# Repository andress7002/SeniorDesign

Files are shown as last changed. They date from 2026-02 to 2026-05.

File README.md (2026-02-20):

# Portable Power Station

This repository contains the hardware and software design files for our Senior Design Project at UTRGV. 

## Overview
Current portable power stations often suffer from poor State-of-Charge (SOC) estimation, inaccurate runtime predictions, and binary failure modes. Our primary objective is to solve this by designing and building an intelligent portable power station that delivers accurate, predictive battery statistics alongside early warnings and predictive thermal management. 

Unlike affordable commercial alternatives, our design integrates a custom high-precision Monitoring Board. This allows for real-time tracking of input/output current, individual cell voltages, and precise battery temperatures to provide an accurate State of Charge (SoC) and true State of Health (SoH).

## Key Specifications
* **Battery Capacity:** 40Ah total capacity utilizing a 3S8P configuration of EVE 50E 21700 cells.
* **Power Outputs:**  120W car lighter output (10A @ 12V)
  * 100W USB-C Power Delivery port
  * 65W USB-C standard port
  * Dual 12W USB-A ports
* **Safety:** Multi-layer protection combining a Daly 40A Battery Management System (BMS) with our custom monitoring board and active cooling.

## System Architecture
The system is controlled by an **STM32F103C8Tx Blue Pill** microcontroller. To simplify the design and communication path, all digital monitors, including the ADCs and the OLED screen, are hosted on a single I2C channel.

**Key Components:**
* **Current Monitoring:** INA series sensor (INA226/INA228) for highly accurate, bidirectional power measurement.
* **Voltage Sensing:** MCP6004 Op-Amp configured for true rail-to-rail I/O to safely step down the maximum cell voltage for the STM32's ADC.
* **Thermal Monitoring:** ADS1115 paired with NTC 10k thermistors to track cell temperatures across the pack.
* **User Interface:** An upgraded OLED display provides real-time feedback to the user on changing battery values.
* **Hardware Integration:** All power, sensing, and control components are being integrated into a custom-manufactured PCB.

## Team Members
* Gonzalo Cervera-Aguinaga
* Darren Mora
* Javier Castro-Frausto
* Andres Sierra Cantu

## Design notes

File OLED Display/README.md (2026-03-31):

# STM32F103C8T6 — SSD1306 OLED Sensor Display

## Wiring

| OLED Pin | STM32 Pin |
|---|---|
| VCC | 3.3V |
| GND | GND |
| SCL | PB6 |
| SDA | PB7 |

| Signal | STM32 Pin |
|---|---|
| External Voltage | PA1 |

---

## What the screen shows

```
┌────────────────────────┐
│    STM32 Sensors       │
│ Temp: 27.4 C           │
│ V_ch1: 1.412 V         │
│ V_ch2: 1.650 V         │
└────────────────────────┘
```

- **Temp** — STM32 internal temperature sensor (~±5°C accuracy)
- **V_ch1** — raw voltage from the internal sensor
- **V_ch2** — voltage measured on PA1 (0 to 3.3V)

Refreshes every 200ms.

---

## Troubleshooting

| Symptom | Fix |
|---|---|
| Blank screen | Check SDA/SCL wiring on PB7/PB6 |
| Wrong temperature | Normal — internal sensor varies per chip |
| V_ch2 always 0 | Check your signal is connected to PA1 |

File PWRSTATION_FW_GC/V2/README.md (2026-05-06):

# PWRSTATION_FW

Bare-metal firmware for an STM32F103C8T6 (Blue Pill) power monitoring station. Reads voltage, current, power, temperature, energy, and charge from a Texas Instruments INA228 85V precision power monitor and displays real-time engineering values on a DIYmall 0.96" SSD1306 I2C OLED display.

---

## Hardware

| Component | Part | Notes |
|---|---|---|
| Microcontroller | STM32F103C8T6 (Blue Pill) | 8 MHz HSI, no PLL |
| Power monitor IC | Texas Instruments INA228 | I2C address 0x40 (A0=A1=GND) |
| Display | DIYmall 0.96" SSD1306 128×64 OLED | I2C address 0x3C |
| Programmer | ST-Link V2 clone | SWD interface |
| Shunt resistor | 1 mΩ | Rated for max expected current |
| Pull-up resistors | 2.2 kΩ × 2 | SDA and SCL to 3.3V rail |

### Pin assignments

| Blue Pill pin | Function | Connected to |
|---|---|---|
| PB6 | I2C1 SCL | INA228 SCL, OLED SCL (shared bus) |
| PB7 | I2C1 SDA | INA228 SDA, OLED SDA (shared bus) |
| PC13 | Onboard LED (active-LOW) | Fault indicator / boot blink |
| PA13 | SWDIO | ST-Link SWDIO |
| PA14 | SWCLK | ST-Link SWCLK |

### INA228 wiring (high-side sensing)

```
Battery+ ──── VBUS
Battery+ ──── IN+  ──── [Rshunt 1mΩ] ──── IN- ──── Load
INA228 VS ─── 3.3V (Blue Pill)
INA228 GND ── GND
INA228 A0 ─── GND  (address bit 0)
INA228 A1 ─── GND  (address bit 1)
INA228 ALERT ─ NC  (not connected)
```

### I2C bus

Both devices share I2C1 on PB6/PB7. Pull-up resistors must connect from each line to the **3.3V rail** — not 5V. 2.2 kΩ gives a calculated rise time of ~186 ns, comfortably within the 300 ns Fast-mode budget.

---

## Software architecture

The firmware is structured as a non-blocking cooperative scheduler driven by `HAL_GetTick()` (1 ms Systick). There is no RTOS.

### Source file structure

```
PWRSTATION_FW/
├── Core/
│   ├── Inc/
│   │   └── main.h                  STM32 HAL includes and Error_Handler declaration
│   └── Src/
│       ├── main.c                  Application entry point and scheduler
│       ├── stm32f1xx_hal_msp.c     HAL peripheral MSP init (GPIO AF, RCC clocks)
│       ├── stm32f1xx_it.c          Interrupt handlers (SysTick_Handler etc.)
│       ├── syscalls.c              Newlib syscall stubs (_write, _read, etc.)
│       └── sysmem.c                Heap implementation for newlib
├── Core/DriversExt/
│   ├── ina228/
│   │   ├── ina228.h                INA228 driver public API and struct definition
│   │   ├── ina228.c                INA228 driver implementation
│   │   └── ina228_regs.h           INA228 register map and bit-field constants
│   └── oled/
│       ├── oled.h                  SSD1306 OLED driver public API
│       └── oled.c                  SSD1306 driver: init, frame buffer, text rendering
├── Drivers/
│   ├── STM32F1xx_HAL_Driver/       STM32 HAL library (ST-provided, do not edit)
│   └── CMSIS/                      ARM CMSIS headers (ST-provided, do not edit)
├── cmake/                          CMake toolchain files generated by STM32CubeMX
├── CMakeLists.txt                  Build system — add new source files here
├── CMakePresets.json               Debug/Release preset configuration
├── STM32F103C8TX_FLASH.ld          Linker script for 64KB flash / 20KB RAM
└── PWRSTATION_FW.ioc               STM32CubeMX project file
```

### Key files explained

**`main.c`** is the application layer. It contains three logical sections:

- `app_init()` — runs once at boot. Initialises the OLED and INA228 over I2C, verifies the INA228 silicon ID, configures the ADC mode and averaging, and resets the energy/charge accumulators. Uses PC13 LED blink codes to signal fault conditions without needing a serial monitor.
- `app_fast_task()` — called every 500 ms by the scheduler. Reads VBUS voltage, shunt voltage, current, power, and die temperature from the INA228 and writes them to OLED rows 0–3.
- `app_slow_task()` — called every 5000 ms. Reads the 40-bit energy and charge accumulators from the INA228 and writes them to OLED rows 4–5.

**`ina228.h` / `ina228.c`** implement the INA228 driver as a self-contained module. The public API covers initialisation, ADC configuration, accumulator reset, and all engineering-unit reads (V, I, P, T, E, Q). All I2C transactions use a finite 500 ms timeout (`INA228_I2C_TIMEOUT_MS`) so the firmware never hangs when the device is absent. A `_i2c_reset()` helper recovers the STM32F1 I2C peripheral from the hardware BUSY lockup bug after any timeout.

**`ina228_regs.h`** defines every INA228 register address and bit-field constant with the `INA228_REG_` prefix to avoid name collisions. Constants cover the full CONFIG, ADC_CONFIG, DIAG_ALRT register maps and known silicon ID values.

**`oled.h` / `oled.c`** implement the SSD1306 OLED driver in two layers. Layer 1 covers hardware primitives: `oled_init()` (full SSD1306 init sequence including charge pump), `oled_flush()` (single 1025-byte I2C burst using horizontal addressing mode), `oled_set_pixel()`, and line/rect drawing helpers. Layer 2 covers text rendering: `oled_print_str()` renders ASCII characters from an embedded 5×7 font stored in Flash, and `oled_printf_row()` formats a full 21-character row using `vsnprintf` and overwrites the entire row to prevent stale digit artifacts.

---

## Scheduler

The main loop is a simple non-blocking timer check with no blocking calls:

```c
while (1)
{
    if (ms_elapsed(s_t_fast) >= INTERVAL_FAST_MS)
    {
        s_t_fast = HAL_GetTick();
        app_fast_task();             // 500 ms: V, I, P, T
    }
    if (ms_elapsed(s_t_slow) >= INTERVAL_SLOW_MS)
    {
        s_t_slow = HAL_GetTick();
        app_slow_task();             // 5000 ms: Energy, Charge
    }
}
```

`ms_elapsed()` handles the 32-bit `HAL_GetTick()` rollover at ~49.7 days of uptime.

---

## Fault blink codes (PC13 LED)

| Pattern | Meaning |
|---|---|
| 3 fast (80 ms) | MCU alive — boot reached app_init |
| 7 medium (200 ms) | OLED not responding on I2C |
| 10 medium (200 ms) | INA228 not responding on I2C |
| 3 medium (200 ms) | INA228 found but silicon ID mismatch |

All faults are non-fatal. The firmware continues running in degraded mode after signalling the fault code.

---

## OLED display layout

```
Row 0   V:  12.345 V     bus voltage
Row 1   I:   3.456 A     load current
Row 2   P:  42.345 W     power
Row 3   T:   27.5 C      INA228 die temperature
Row 4   E: 1234.5 J      energy accumulator
Row 5   Q:  567.8 C      charge accumulator
Row 6   (reserved)
Row 7   (reserved)
```

Font: 5×7 pixel glyphs with 1-pixel column gap, 6 px per character, 21 characters × 8 rows on 128×64.

---

## INA228 configuration

| Parameter | Value | Notes |
|---|---|---|
| Shunt resistance | 1 mΩ | `INA228_SHUNT_OHMS` in main.c |
| Max expected current | 40 A | `INA228_MAX_AMPS` in main.c |
| Current LSB | ~76.3 nA/LSB | Computed as Imax / 2^19 |
| ADC mode | Continuous all | Shunt + bus + temperature |
| Conversion time | 1052 µs | Per channel |
| Averaging | 64 samples | ~67 ms total conversion cycle |
| I2C address | 0x40 | A0=GND, A1=GND |

To change shunt resistance or current range, update only the two defines in `main.c`. The driver recomputes `SHUNT_CAL`, `current_lsb`, and `power_lsb` automatically.

---

## Build environment

| Tool | Version |
|---|---|
| IDE | VS Code + STM32CubeMX VS Code extension |
| Compiler | GNU Arm Embedded Toolchain (arm-none-eabi-gcc) 13.3.1 |
| Build system | CMake 4.0 + Ninja |
| HAL | STM32F1xx HAL Driver (CubeMX generated) |
| Language standard | C11 |

### Building

Clone the repository, open the folder in VS Code with the STM32CubeMX extension installed, and click **Build**. The extension handles CMake configuration automatically using `CMakePresets.json`.

To rebuild from scratch delete the `build/` directory and rebuild.

### Flashing

Connect the ST-Link V2 to the Blue Pill SWD header (SWDIO → PA13, SWCLK → PA14, 3.3V, GND), then click **Run and Debug** in VS Code. Verify BOOT0 jumper is set to 0 (GND) before flashing.

### Modifying CubeMX configuration

Open `PWRSTATION_FW.ioc` in STM32CubeMX. After making changes click **Generate Code**. CubeMX preserves all user code inside `/* USER CODE BEGIN */` / `/* USER CODE END */` markers. Always back up `main.c` before regenerating as a precaution.

---

## Adding this repository's driver files after CubeMX regeneration

CubeMX does not know about `Core/DriversExt/`. After regenerating, verify `CMakeLists.txt` still contains these entries:

```cmake
target_sources(${CMAKE_PROJECT_NAME} PRIVATE
    ...
    Core/DriversExt/ina228/ina228.c
    Core/DriversExt/oled/oled.c
)

target_include_directories(${CMAKE_PROJECT_NAME} PRIVATE
    ...
    Core/DriversExt/ina228
    Core/DriversExt/oled
)
```

CubeMX will not remove these lines (they are outside its managed sections) but it may reformat the file — verify after every regeneration.

---

## License

STM32 HAL library files under `Drivers/` are copyright STMicroelectronics and licensed under BSD 3-Clause. Application code in `Core/` and `Core/DriversExt/` is provided as-is.

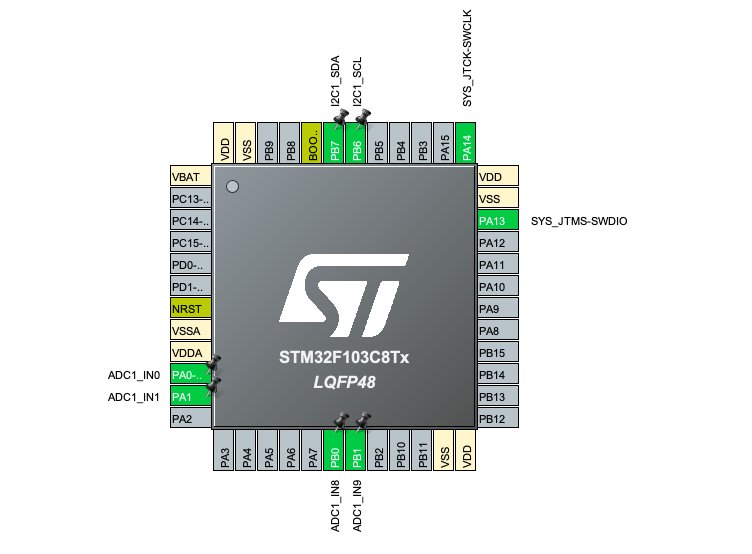
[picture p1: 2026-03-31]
OLED Display/cubemx_pinout.png

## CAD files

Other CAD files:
PCB Design/SENIOR_DESIGN_CASE.f3d
PCB Design/SENIOR_FINAL_CASE.f3d
PCB Design/SENIOR_FINAL_CASE_UPDATE1.f3d

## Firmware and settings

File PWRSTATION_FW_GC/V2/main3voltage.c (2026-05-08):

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

/* Includes ------------------------------------------------------------------*/
/* USER CODE BEGIN Includes */
#include "main.h"
#include <stdio.h>
#include <math.h>
#include "ina228.h"
#include "oled.h"
/* USER CODE END Includes */

/* USER CODE BEGIN PD */

/* -- INA228 ----------------------------------------------------------------- */
#define INA228_I2C_ADDR    0x40
#define INA228_SHUNT_OHMS  0.001f
#define INA228_MAX_AMPS    40.0f

/* -- OLED ------------------------------------------------------------------- */
#define OLED_I2C_ADDR      0x3C

/* -- Scheduler intervals ---------------------------------------------------- */
#define INTERVAL_FAST_MS   500U
#define INTERVAL_SLOW_MS   5000U

/* -- NTC thermistor parameters ---------------------------------------------- */
#define R_FIXED        10000.0f
#define R_NOMINAL      11000.0f
#define T_NOMINAL      25.0f
#define B_COEFFICIENT  3950.0f
#define V_SUPPLY       3.3f
#define ADC_RESOLUTION 4095.0f

/* -- Cell voltage sensing (MCP6004 gain = 2/3, so inverse = x1.5) ---------- */
#define CELL_GAIN_INV  1.5f
#define CELL_VOLT_MIN  2.5f
#define CELL_VOLT_MAX  4.2f

/* USER CODE END PD */

/* USER CODE BEGIN PM */
#define LED_ON()   HAL_GPIO_WritePin(GPIOC, GPIO_PIN_13, GPIO_PIN_RESET)
#define LED_OFF()  HAL_GPIO_WritePin(GPIOC, GPIO_PIN_13, GPIO_PIN_SET)
#define LED_TOG()  HAL_GPIO_TogglePin(GPIOC, GPIO_PIN_13)
/* USER CODE END PM */

ADC_HandleTypeDef  hadc1;
I2C_HandleTypeDef  hi2c1;
TIM_HandleTypeDef  htim1;
UART_HandleTypeDef huart1;

/* USER CODE BEGIN PV */

/* -- INA228 ----------------------------------------------------------------- */
static ina228_t  g_ina;
static uint8_t   g_ina_ok   = 0U;

volatile float   g_current_A = 0.0f;
volatile float   g_power_W   = 0.0f;
volatile float   g_dietemp_C = 0.0f;
volatile double  g_energy_J  = 0.0;
volatile double  g_charge_C  = 0.0;
volatile uint8_t g_ina_err   = 0U;

/* -- Cell voltages (PA2=C1, PA3=C2, PA4=C3) -------------------------------- */
volatile float   g_vcell1    = 0.0f;
volatile float   g_vcell2    = 0.0f;
volatile float   g_vcell3    = 0.0f;

/* -- NTC thermistors (PA0=T1, PA1=T2) -------------------------------------- */
volatile float   temp_t1     = 0.0f;
volatile float   temp_t2     = 0.0f;

/* -- Scheduler timestamps --------------------------------------------------- */
static uint32_t s_t_fast = 0U;
static uint32_t s_t_slow = 0U;

/* USER CODE END PV */

void SystemClock_Config(void);
static void MX_GPIO_Init(void);
static void MX_ADC1_Init(void);
static void MX_I2C1_Init(void);
static void MX_TIM1_Init(void);
static void MX_USART1_UART_Init(void);

/* USER CODE BEGIN PFP */
static void     led_blink(uint8_t count, uint32_t on_ms, uint32_t off_ms);
static void     app_init(void);
static void     app_fast_task(void);
static void     app_slow_task(void);
static uint32_t ms_elapsed(uint32_t since);
static void     I2C1_BusRecovery(void);
static uint8_t  ADC_SelectChannel(uint32_t channel);
static uint16_t ADC_ReadRaw(uint32_t channel);
static float    NTC_ToTemperature(float v);
static float    CellADC_ToVoltage(uint32_t channel);
/* USER CODE END PFP */

/* USER CODE BEGIN 0 */

static uint32_t ms_elapsed(uint32_t since)
{
    uint32_t now = HAL_GetTick();
    return (now >= since) ? (now - since)
                          : (0xFFFFFFFFU - since + now + 1U);
}

static void led_blink(uint8_t count, uint32_t on_ms, uint32_t off_ms)
{
    for (uint8_t i = 0; i < count; i++)
    {
        LED_ON();  HAL_Delay(on_ms);
        LED_OFF(); HAL_Delay(off_ms);
    }
}

static uint8_t ADC_SelectChannel(uint32_t channel)
{
    ADC_ChannelConfTypeDef sConfig = {0};
    sConfig.Channel      = channel;
    sConfig.Rank         = ADC_REGULAR_RANK_1;
    sConfig.SamplingTime = ADC_SAMPLETIME_239CYCLES_5;
    if (HAL_ADC_ConfigChannel(&hadc1, &sConfig) != HAL_OK)
        return 0;
    return 1;
}

static uint16_t ADC_ReadRaw(uint32_t channel)
{
    if (!ADC_SelectChannel(channel)) return 0;
    if (HAL_ADC_Start(&hadc1) != HAL_OK) return 0;
    if (HAL_ADC_PollForConversion(&hadc1, 100U) != HAL_OK)
    {
        HAL_ADC_Stop(&hadc1);
        return 0;
    }
    uint16_t val = (uint16_t)HAL_ADC_GetValue(&hadc1);
    HAL_ADC_Stop(&hadc1);
    return val;
}

static float NTC_ToTemperature(float v)
{
    if (v >= V_SUPPLY) return -273.15f;
    if (v <= 0.0f)     return -273.15f;
    float r_ntc     = R_FIXED * v / (V_SUPPLY - v);
    float steinhart = logf(r_ntc / R_NOMINAL);
    steinhart /= B_COEFFICIENT;
    steinhart += 1.0f / (T_NOMINAL + 273.15f);
    steinhart  = 1.0f / steinhart;
    return steinhart - 273.15f;
}

static float CellADC_ToVoltage(uint32_t channel)
{
    uint16_t raw = ADC_ReadRaw(channel);
    float    v   = ((float)raw * V_SUPPLY) / ADC_RESOLUTION;
    return v * CELL_GAIN_INV;   /* undo MCP6004 2/3 gain */
}

/* ── Application tasks ──────────────────────────────────────────────────── */

static void app_init(void)
{
    led_blink(3, 80, 80);
    HAL_Delay(400);

    oled_status_t oled_s = oled_init(&hi2c1, OLED_I2C_ADDR);
    if (oled_s != OLED_OK)
    {
        led_blink(7, 200, 200);
    }
    else
    {
        oled_clear();
        oled_print_str(0, 0, "PWRSTATION FW");
        oled_print_str(0, 1, "Init...");
        oled_flush();
    }

    ina228_status_t ina_s = ina228_init(&g_ina, &hi2c1,
                                         INA228_I2C_ADDR,
                                         INA228_SHUNT_OHMS,
                                         INA228_MAX_AMPS);
    if (ina_s != INA228_OK)
    {
        led_blink(10, 200, 200);
        g_ina_ok = 0U;
        if (oled_s == OLED_OK)
        {
            oled_clear();
            oled_print_str(0, 0, "INA228 MISSING");
            oled_print_str(0, 1, "Cell+NTC only");
            oled_flush();
            HAL_Delay(2000);
        }
        return;
    }

    if (ina228_check_id(&g_ina) != INA228_OK)
    {
        led_blink(3, 200, 200);
        g_ina_ok = 0U;
        if (oled_s == OLED_OK)
        {
            oled_clear();
            oled_print_str(0, 0, "INA228 BAD ID");
            oled_flush();
            HAL_Delay(2000);
        }
        return;
    }

    ina228_set_adc_config(&g_ina,
        INA228_REG_MODE_CONT_ALL |
        INA228_REG_VBUSCT_1052US |
        INA228_REG_VSHCT_1052US  |
        INA228_REG_VTCT_1052US   |
        INA228_REG_AVG_64);

    ina228_reset_accumulators(&g_ina);
    g_ina_ok = 1U;

    if (oled_s == OLED_OK)
    {
        oled_clear();
        oled_print_str(0, 0, "PWRSTATION FW");
        oled_print_str(0, 1, "INA228 OK");
        oled_flush();
        HAL_Delay(1000);
    }
}

/**
  * @brief  Fast task — 500 ms cadence.
  *
  *   Row 0  C1:  3.712 V       Cell 1 (PA2)   [!! CELL FAULT !! if out of range]
  *   Row 1  C2:  3.708 V       Cell 2 (PA3)
  *   Row 2  C3:  3.715 V       Cell 3 (PA4)
  *   Row 3  I:   3.4560 A      INA228 current
  *   Row 4  P:  42.345 W       INA228 power
  *   Row 5  E: 1234.5  J       INA228 energy  (written by slow task)
  *   Row 6  T1:  25.3 C        NTC thermistor 1 (PA0)
  *   Row 7  T2:  31.7 C        NTC thermistor 2 (PA1)
  */
static void app_fast_task(void)
{
    /* ── Cell voltages (PA2/PA3/PA4) -> rows 0-2 ─────────────────────────── */
    g_vcell1 = CellADC_ToVoltage(ADC_CHANNEL_2);
    g_vcell2 = CellADC_ToVoltage(ADC_CHANNEL_3);
    g_vcell3 = CellADC_ToVoltage(ADC_CHANNEL_4);

    uint8_t cell_fault = (g_vcell1 < CELL_VOLT_MIN || g_vcell1 > CELL_VOLT_MAX ||
                          g_vcell2 < CELL_VOLT_MIN || g_vcell2 > CELL_VOLT_MAX ||
                          g_vcell3 < CELL_VOLT_MIN || g_vcell3 > CELL_VOLT_MAX) ? 1U : 0U;

    if (cell_fault)
        oled_printf_row(0, "!! CELL FAULT !!");
    else
        oled_printf_row(0, "C1:%6.3fV", (double)g_vcell1);

    oled_printf_row(1, "C2:%6.3fV", (double)g_vcell2);
    oled_printf_row(2, "C3:%6.3fV", (double)g_vcell3);

    /* ── INA228 current + power -> rows 3-4 ─────────────────────────────── */
    if (g_ina_ok)
    {
        ina228_status_t s = INA228_OK;
        s |= ina228_get_current_A(&g_ina, (float *)&g_current_A);
        s |= ina228_get_power_W  (&g_ina, (float *)&g_power_W);
        s |= ina228_get_dietemp_C(&g_ina, (float *)&g_dietemp_C);

        if (s != INA228_OK)
        {
            g_ina_err++;
            oled_printf_row(3, "INA228 ERR");
            oled_printf_row(4, "");
        }
        else
        {
            g_ina_err = 0U;
            oled_printf_row(3, "I:%7.4fA", (double)g_current_A);
            oled_printf_row(4, "P:%7.3fW",  (double)g_power_W);
        }
    }
    else
    {
        oled_printf_row(3, "I:    --- A");
        oled_printf_row(4, "P:    --- W");
    }

    /* ── NTC thermistors (PA0=T1, PA1=T2) -> rows 6-7 ───────────────────── */
    temp_t1 = NTC_ToTemperature(((float)ADC_ReadRaw(ADC_CHANNEL_0) * V_SUPPLY) / ADC_RESOLUTION);
    temp_t2 = NTC_ToTemperature(((float)ADC_ReadRaw(ADC_CHANNEL_1) * V_SUPPLY) / ADC_RESOLUTION);

    oled_printf_row(6, "T1:%5.1fC", (double)temp_t1);
    oled_printf_row(7, "T2:%5.1fC", (double)temp_t2);

    oled_flush();
}

/**
  * @brief  Slow task — 5000 ms cadence.  Energy accumulator -> row 5.
  */
static void app_slow_task(void)
{
    if (!g_ina_ok) return;

    ina228_status_t s = INA228_OK;
    s |= ina228_get_energy_J(&g_ina, (double *)&g_energy_J);
    s |= ina228_get_charge_C(&g_ina, (double *)&g_charge_C);

    if (s != INA228_OK) { g_ina_err++; return; }

    oled_printf_row(5, "E:%7.1fJ", g_energy_J);
    oled_flush();
}

static void I2C1_BusRecovery(void)
{
    GPIO_InitTypeDef GPIO_InitStruct = {0};

    __HAL_RCC_GPIOB_CLK_ENABLE();
    __HAL_RCC_I2C1_FORCE_RESET();
    HAL_Delay(10);
    __HAL_RCC_I2C1_RELEASE_RESET();

    GPIO_InitStruct.Pin   = GPIO_PIN_6 | GPIO_PIN_7;
    GPIO_InitStruct.Mode  = GPIO_MODE_OUTPUT_OD;
    GPIO_InitStruct.Pull  = GPIO_NOPULL;
    GPIO_InitStruct.Speed = GPIO_SPEED_FREQ_LOW;
    HAL_GPIO_Init(GPIOB, &GPIO_InitStruct);

    HAL_GPIO_WritePin(GPIOB, GPIO_PIN_6 | GPIO_PIN_7, GPIO_PIN_SET);
    HAL_Delay(1);

    for (uint8_t i = 0; i < 9; i++)
    {
        HAL_GPIO_WritePin(GPIOB, GPIO_PIN_6, GPIO_PIN_RESET);
        HAL_Delay(1);
        HAL_GPIO_WritePin(GPIOB, GPIO_PIN_6, GPIO_PIN_SET);
        HAL_Delay(1);
        if (HAL_GPIO_ReadPin(GPIOB, GPIO_PIN_7) == GPIO_PIN_SET)
            break;
    }

    HAL_GPIO_WritePin(GPIOB, GPIO_PIN_7, GPIO_PIN_RESET);
    HAL_Delay(1);
    HAL_GPIO_WritePin(GPIOB, GPIO_PIN_6, GPIO_PIN_SET);
    HAL_Delay(1);
    HAL_GPIO_WritePin(GPIOB, GPIO_PIN_7, GPIO_PIN_SET);
    HAL_Delay(1);

    HAL_GPIO_DeInit(GPIOB, GPIO_PIN_6 | GPIO_PIN_7);
}

/* USER CODE END 0 */

int main(void)
{
    HAL_Init();
    SystemClock_Config();

    /* USER CODE BEGIN SysInit */
    I2C1_BusRecovery();
    /* USER CODE END SysInit */

    MX_GPIO_Init();
    MX_ADC1_Init();
    MX_I2C1_Init();
    MX_TIM1_Init();
    MX_USART1_UART_Init();

    /* USER CODE BEGIN 2 */
    app_init();
    s_t_fast = HAL_GetTick();
    s_t_slow = HAL_GetTick();
    /* USER CODE END 2 */

    while (1)
    {
        /* USER CODE BEGIN 3 */
        if (ms_elapsed(s_t_fast) >= INTERVAL_FAST_MS)
        {
            s_t_fast = HAL_GetTick();
            LED_TOG();
            app_fast_task();
        }

        if (ms_elapsed(s_t_slow) >= INTERVAL_SLOW_MS)
        {
            s_t_slow = HAL_GetTick();
            app_slow_task();
        }
        /* USER CODE END 3 */
    }
}

void SystemClock_Config(void)
{
    RCC_OscInitTypeDef       RCC_OscInitStruct = {0};
    RCC_ClkInitTypeDef       RCC_ClkInitStruct = {0};
    RCC_PeriphCLKInitTypeDef PeriphClkInit     = {0};

    RCC_OscInitStruct.OscillatorType      = RCC_OSCILLATORTYPE_HSI;
    RCC_OscInitStruct.HSIState            = RCC_HSI_ON;
    RCC_OscInitStruct.HSICalibrationValue = RCC_HSICALIBRATION_DEFAULT;
    RCC_OscInitStruct.PLL.PLLState        = RCC_PLL_NONE;
    if (HAL_RCC_OscConfig(&RCC_OscInitStruct) != HAL_OK)
        Error_Handler();

    RCC_ClkInitStruct.ClockType      = RCC_CLOCKTYPE_HCLK | RCC_CLOCKTYPE_SYSCLK
                                     | RCC_CLOCKTYPE_PCLK1 | RCC_CLOCKTYPE_PCLK2;
    RCC_ClkInitStruct.SYSCLKSource   = RCC_SYSCLKSOURCE_HSI;
    RCC_ClkInitStruct.AHBCLKDivider  = RCC_SYSCLK_DIV1;
    RCC_ClkInitStruct.APB1CLKDivider = RCC_HCLK_DIV1;
    RCC_ClkInitStruct.APB2CLKDivider = RCC_HCLK_DIV1;
    if (HAL_RCC_ClockConfig(&RCC_ClkInitStruct, FLASH_LATENCY_0) != HAL_OK)
        Error_Handler();

    PeriphClkInit.PeriphClockSelection = RCC_PERIPHCLK_ADC;
    PeriphClkInit.AdcClockSelection    = RCC_ADCPCLK2_DIV2;
    if (HAL_RCCEx_PeriphCLKConfig(&PeriphClkInit) != HAL_OK)
        Error_Handler();
}

static void MX_ADC1_Init(void)
{
    ADC_ChannelConfTypeDef sConfig = {0};

    hadc1.Instance                   = ADC1;
    hadc1.Init.ScanConvMode          = ADC_SCAN_DISABLE;
    hadc1.Init.ContinuousConvMode    = DISABLE;
    hadc1.Init.DiscontinuousConvMode = DISABLE;
    hadc1.Init.ExternalTrigConv      = ADC_SOFTWARE_START;
    hadc1.Init.DataAlign             = ADC_DATAALIGN_RIGHT;
    hadc1.Init.NbrOfConversion       = 1;
    if (HAL_ADC_Init(&hadc1) != HAL_OK)
        Error_Handler();

    /* Default CH0 (PA0/T1) — ADC_SelectChannel() overrides at runtime
     * Channels in use:
     *   CH0 (PA0) T1 NTC
     *   CH1 (PA1) T2 NTC
     *   CH2 (PA2) Cell 1 op-amp output
     *   CH3 (PA3) Cell 2 op-amp output
     *   CH4 (PA4) Cell 3 op-amp output        */
    sConfig.Channel      = ADC_CHANNEL_0;
    sConfig.Rank         = ADC_REGULAR_RANK_1;
    sConfig.SamplingTime = ADC_SAMPLETIME_239CYCLES_5;
    if (HAL_ADC_ConfigChannel(&hadc1, &sConfig) != HAL_OK)
        Error_Handler();
}

static void MX_I2C1_Init(void)
{
    hi2c1.Instance             = I2C1;
    hi2c1.Init.ClockSpeed      = 400000;
    hi2c1.Init.DutyCycle       = I2C_DUTYCYCLE_2;
    hi2c1.Init.OwnAddress1     = 0;
    hi2c1.Init.AddressingMode  = I2C_ADDRESSINGMODE_7BIT;
    hi2c1.Init.DualAddressMode = I2C_DUALADDRESS_DISABLE;
    hi2c1.Init.OwnAddress2     = 0;
    hi2c1.Init.GeneralCallMode = I2C_GENERALCALL_DISABLE;
    hi2c1.Init.NoStretchMode   = I2C_NOSTRETCH_DISABLE;
    if (HAL_I2C_Init(&hi2c1) != HAL_OK)
        Error_Handler();
}

static void MX_TIM1_Init(void)
{
    TIM_ClockConfigTypeDef  sClockSourceConfig = {0};
    TIM_MasterConfigTypeDef sMasterConfig      = {0};

    htim1.Instance               = TIM1;
    htim1.Init.Prescaler         = 7;
    htim1.Init.CounterMode       = TIM_COUNTERMODE_UP;
    htim1.Init.Period            = 65535;
    htim1.Init.ClockDivision     = TIM_CLOCKDIVISION_DIV1;
    htim1.Init.RepetitionCounter = 0;
    htim1.Init.AutoReloadPreload = TIM_AUTORELOAD_PRELOAD_DISABLE;
    if (HAL_TIM_Base_Init(&htim1) != HAL_OK)
        Error_Handler();

    sClockSourceConfig.ClockSource = TIM_CLOCKSOURCE_INTERNAL;
    if (HAL_TIM_ConfigClockSource(&htim1, &sClockSourceConfig) != HAL_OK)
        Error_Handler();

    sMasterConfig.MasterOutputTrigger = TIM_TRGO_RESET;
    sMasterConfig.MasterSlaveMode     = TIM_MASTERSLAVEMODE_DISABLE;
    if (HAL_TIMEx_MasterConfigSynchronization(&htim1, &sMasterConfig) != HAL_OK)
        Error_Handler();

    HAL_TIM_Base_Start(&htim1);
}

static void MX_USART1_UART_Init(void)
{
    huart1.Instance          = USART1;
    huart1.Init.BaudRate     = 115200;
    huart1.Init.WordLength   = UART_WORDLENGTH_8B;
    huart1.Init.StopBits     = UART_STOPBITS_1;
    huart1.Init.Parity       = UART_PARITY_NONE;
    huart1.Init.Mode         = UART_MODE_TX_RX;
    huart1.Init.HwFlowCtl    = UART_HWCONTROL_NONE;
    huart1.Init.OverSampling = UART_OVERSAMPLING_16;
    if (HAL_UART_Init(&huart1) != HAL_OK)
        Error_Handler();
}

static void MX_GPIO_Init(void)
{
    GPIO_InitTypeDef GPIO_InitStruct = {0};

    __HAL_RCC_GPIOC_CLK_ENABLE();
    __HAL_RCC_GPIOA_CLK_ENABLE();
    __HAL_RCC_GPIOB_CLK_ENABLE();

    /* PC13 — onboard LED, active-LOW */
    HAL_GPIO_WritePin(GPIOC, GPIO_PIN_13, GPIO_PIN_SET);
    GPIO_InitStruct.Pin   = GPIO_PIN_13;
    GPIO_InitStruct.Mode  = GPIO_MODE_OUTPUT_PP;
    GPIO_InitStruct.Pull  = GPIO_NOPULL;
    GPIO_InitStruct.Speed = GPIO_SPEED_FREQ_LOW;
    HAL_GPIO_Init(GPIOC, &GPIO_InitStruct);

    /* PA0-PA4 left as analog inputs — HAL_ADC_Init() configures them.
     * Do NOT drive these pins as digital outputs.                     */
}

void Error_Handler(void)
{
    __disable_irq();
    while (1) { }
}

#ifdef USE_FULL_ASSERT
void assert_failed(uint8_t *file, uint32_t line)
{
    (void)file; (void)line;
}
#endif

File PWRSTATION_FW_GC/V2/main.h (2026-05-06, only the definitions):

#define GREEN_LED_Pin GPIO_PIN_13
#define GREEN_LED_GPIO_Port GPIOC
#define OLED_RST_Pin GPIO_PIN_0
#define OLED_RST_GPIO_Port GPIOA

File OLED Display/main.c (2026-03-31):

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
/* Includes ------------------------------------------------------------------*/
#include "main.h"

/* USER CODE BEGIN Includes */
#include "ssd1306.h"
#include "ssd1306_fonts.h"
#include <stdio.h>  // for sprintf
/* USER CODE END Includes */

ADC_HandleTypeDef hadc1;

I2C_HandleTypeDef hi2c1;

/* USER CODE BEGIN PV */

static char display_buf[32];  // scratch buffer for sprintf

#define STM32_SENSOR_1_CHANNEL  ADC_CHANNEL_TEMPSENSOR
#define STM32_SENSOR_2_CHANNEL  ADC_CHANNEL_1

static uint16_t raw_ch1 = 0;
static uint16_t raw_ch2 = 0;
static float voltage_ch1 = 0.0f;
static float voltage_ch2 = 0.0f;

static float temp_ch1 = 0.0f;
/* USER CODE END PV */

void SystemClock_Config(void);
static void MX_GPIO_Init(void);
static void MX_ADC1_Init(void);
static void MX_I2C1_Init(void);
/* USER CODE BEGIN PFP */
static uint8_t STM32_ADC_SelectChannel(uint32_t channel);
static uint16_t STM32_ADC_ReadRaw(uint32_t channel);
static float STM32_ADC_RawToVoltage(uint16_t raw);
/* USER CODE END PFP */

/* USER CODE BEGIN 0 */
static uint8_t STM32_ADC_SelectChannel(uint32_t channel)
{
  ADC_ChannelConfTypeDef sConfig = {0};

  sConfig.Channel = channel;
  sConfig.Rank = ADC_REGULAR_RANK_1;
  sConfig.SamplingTime = ADC_SAMPLETIME_239CYCLES_5;

  if (HAL_ADC_ConfigChannel(&hadc1, &sConfig) != HAL_OK)
  {
    return 0;
  }

  return 1;
}

static uint16_t STM32_ADC_ReadRaw(uint32_t channel)
{
  if (!STM32_ADC_SelectChannel(channel))
  {
    return 0;
  }

  if (HAL_ADC_Start(&hadc1) != HAL_OK)
  {
    return 0;
  }

  if (HAL_ADC_PollForConversion(&hadc1, HAL_MAX_DELAY) != HAL_OK)
  {
    HAL_ADC_Stop(&hadc1);
    return 0;
  }

  {
    uint16_t raw = (uint16_t)HAL_ADC_GetValue(&hadc1);
    HAL_ADC_Stop(&hadc1);
    return raw;
  }
}

static float STM32_ADC_RawToVoltage(uint16_t raw)
{
  return ((float)raw * 3.3f) / 4095.0f;
}
/* USER CODE END 0 */

/**
  * @brief  The application entry point.
  * @retval int
  */
int main(void)
{

  /* MCU Configuration--------------------------------------------------------*/

  /* Reset of all peripherals, Initializes the Flash interface and the Systick. */
  HAL_Init();

  /* Configure the system clock */
  SystemClock_Config();

  /* Initialize all configured peripherals */
  MX_GPIO_Init();
  MX_ADC1_Init();
  MX_I2C1_Init();
  /* USER CODE BEGIN 2 */
  ssd1306_Init();

  ssd1306_Fill(Black);
  ssd1306_SetCursor(10, 20);
  ssd1306_WriteString("Initializing...", Font_7x10, White);
  ssd1306_UpdateScreen();
  HAL_Delay(1000);
  /* USER CODE END 2 */

  /* Infinite loop */
  /* USER CODE BEGIN WHILE */
  while (1)
  {
    /* USER CODE END WHILE */

    /* USER CODE BEGIN 3 */
	  raw_ch1 = STM32_ADC_ReadRaw(STM32_SENSOR_1_CHANNEL);
	  raw_ch2 = STM32_ADC_ReadRaw(STM32_SENSOR_2_CHANNEL);

	  voltage_ch1 = STM32_ADC_RawToVoltage(raw_ch1);
	  voltage_ch2 = STM32_ADC_RawToVoltage(raw_ch2);

	  temp_ch1 = ((1.43f - voltage_ch1) / 0.0043f) + 25.0f;

	  // --- OLED Display Update ---
	  ssd1306_Fill(Black);  // clear screen

	  // Line 1: Title
	  ssd1306_SetCursor(20, 0);
	  ssd1306_WriteString("STM32 Sensors", Font_7x10, White);

	  // Line 2: Internal temperature
	  sprintf(display_buf, "Temp: %.1f C", temp_ch1);
	  ssd1306_SetCursor(0, 16);
	  ssd1306_WriteString(display_buf, Font_7x10, White);

	  // Line 3: CH1 voltage (internal sensor raw voltage)
	  sprintf(display_buf, "V_ch1: %.3f V", voltage_ch1);
	  ssd1306_SetCursor(0, 32);
	  ssd1306_WriteString(display_buf, Font_7x10, White);

	  // Line 4: CH2 voltage (PA1 external)
	  sprintf(display_buf, "V_ch2: %.3f V", voltage_ch2);
	  ssd1306_SetCursor(0, 48);
	  ssd1306_WriteString(display_buf, Font_7x10, White);

	  ssd1306_UpdateScreen();  // push buffer to display

	  HAL_Delay(200);
    /* USER CODE END 3 */
  }
}

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
/* USER CODE BEGIN 4 */
/*
 * STM32-only voltage test stage:
 * - Reads PA0 as ADC1_IN0
 * - Reads PA1 as ADC1_IN1
 * - Stores raw ADC counts in raw_ch1/raw_ch2
 * - Stores converted voltages in voltage_ch1/voltage_ch2
 */
/* USER CODE END 4 */
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


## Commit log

2026-02-19 PCB Folder added
2026-03-31 OLED display output via SSD1306 I2C
2026-04-09 main2.c
    This main file is to test the code without using the Oled Display is the same as the other one but the code from the display is commented out so it doesnt interfere with the debugging
    [main (1).c]
2026-04-10 Main to read the temperature from the thermsistor voltage divider
2026-05-08 Added the merged main
    Here is the code for the new main.c that merged the thermistors and the INA code
2026-05-08 main 3 with the voltage sensing system

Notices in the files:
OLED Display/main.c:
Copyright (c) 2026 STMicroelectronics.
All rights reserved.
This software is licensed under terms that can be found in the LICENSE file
